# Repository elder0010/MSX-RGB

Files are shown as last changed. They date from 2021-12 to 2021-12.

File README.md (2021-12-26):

# TMS9929A / TMS9928A RGB
## A RGB demodulator for TMS9929A / TMS9928A chip, mostly used on MSX computers and Colecovision. 

This board outputs RGB+CSYNC from the original YPbPr chip channels of the TMS99 chip. 
Output from each color channel can be adjusted using a trimmer. 
Based on the [Universele interface RGB op MSX1 en SV.328](http://www.msxarchive.nl/pub/msx/mirrors/hanso/hwdoityourself/rgbmsx1.pdf). Mine fixes the emitter follower transistors of this version.
This repository contains the KiCad project and the Gerber files, the [PDF schematics](https://github.com/elder0010/msx_rgb/blob/main/TMS9929_RGB_Adapter.pdf) and the [BOM](https://github.com/elder0010/msx_rgb/blob/main/TMS9929_RGB_Adapter.csv) file.

## Features
- Each channel can be tuned
- Provides audio output pin
- Provides 5V output pin (if you want to use it with an RGB Scart cable for "modern" TVs)
- Fits into the MSX composite modulator slot
- Extremely cheap!

## Video
TMS99 RGB BOARD (https://www.youtube.com/watch?v=eCPy9jgGLzQ)

## Sample output (photo taken on BVM 20DU)
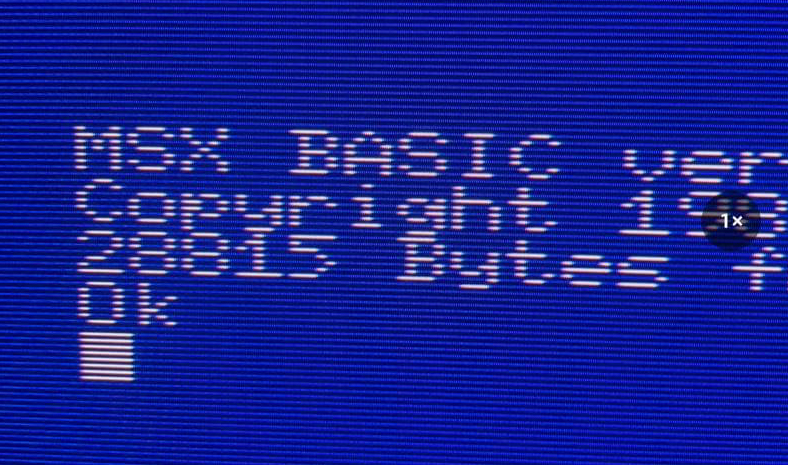
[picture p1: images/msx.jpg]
VIDEO OUT


## Assembled PCB
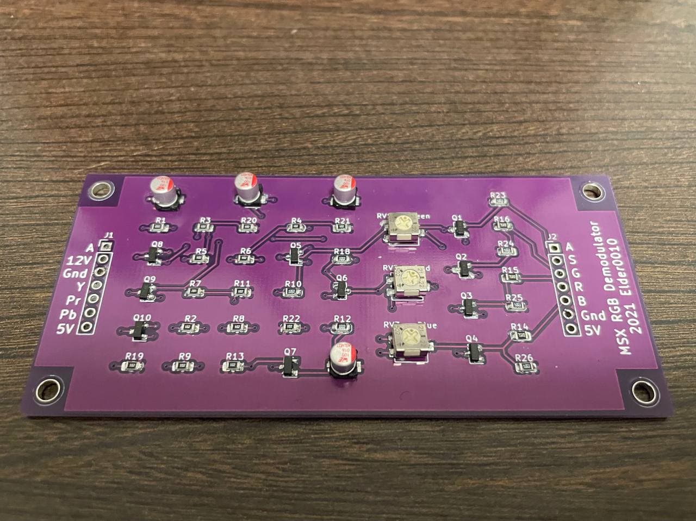
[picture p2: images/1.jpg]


## The PCB in a Phonola VG-8020
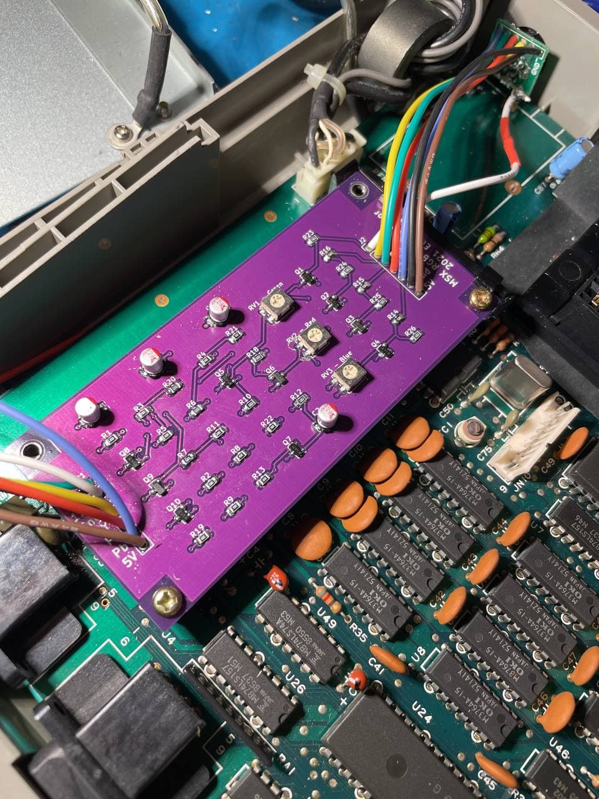
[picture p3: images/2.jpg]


## How to assemble
- Y, Pb, Pr signals must be taken directly from the TMS chip (pin 35,36,38 on TMS9928A or TMS9929A)
- Audio is from pin 4 of the AY38910
- 5V pin is optional: wire it only if you need to connect the computer to a scart TV.
- Removing the original composite modulator (on MSX) is not mandatory but encouraged: unfortunately it creates noises also on the RGB interface. Keep in mind that removing the modulator will disable the composite video and the RF video out of the machine.
- On the Phonola VG8020 I removed the RF modulator to make room for a 8 pin mini din connector. I used the [8pin Mini DIN to EuroSCART PACKAPUNCH cable for RGB modified consoles](https://www.retrogamingcables.co.uk/atari/8PIN-MINI-DIN-TO-RGB-EUROSCART-TIM-WORTHINGTON-NES-RGB-ATARI-2600-HAS-SUPERGUN-Sega-Game-Gear-Philips-CDi-Colecovision-Inte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). It's possible also to desolder the original composite out connector and use a 8 pin DIN connector to make it compatible with a Sega Genesis 1 SCART cable.

## External view of the mini din connector (RF modulator has been removed)
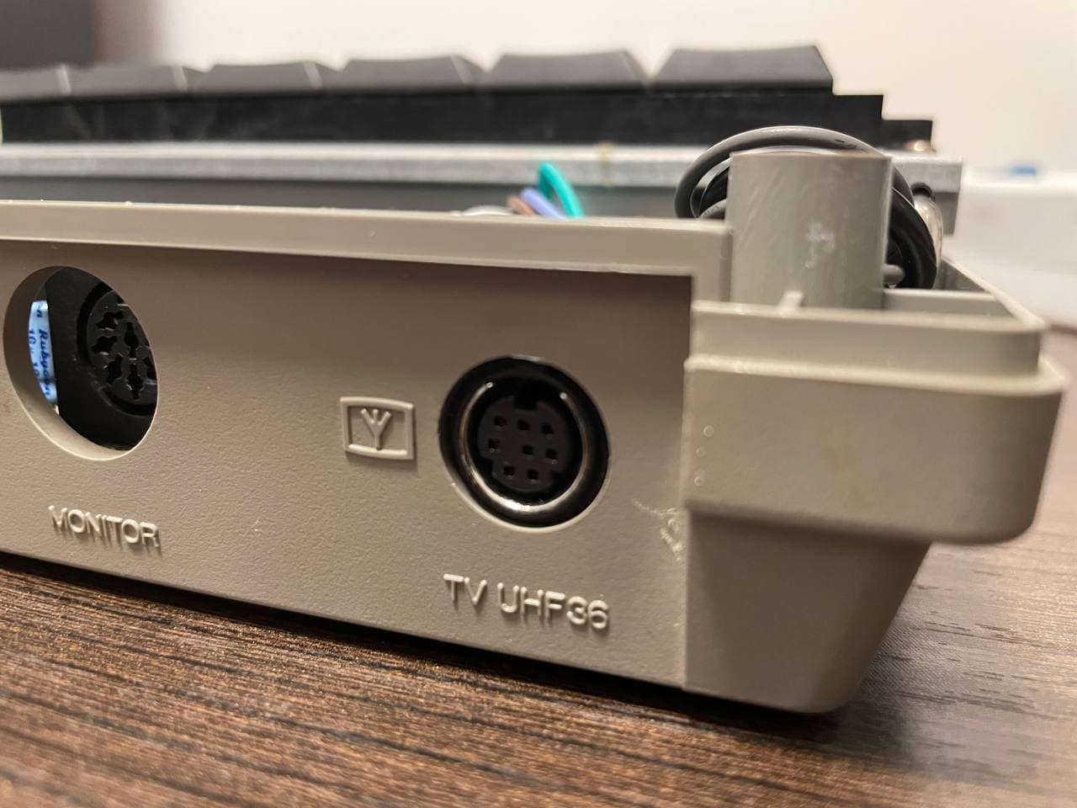
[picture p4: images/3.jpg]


## Perks
This board provides an RGB output for the TMS9929A / TMS9928A chip.
Although it's impossible to have 100% correct colours, it's possible to obtain a palette very close to the correct one in this way:
- Set each RGB trimmer to 0
- Turn up a little the RED and GREEN potentiometer until something visible appears on screen
- Turn up the BLUE potentiometer until the background becomes blueish - keep in mind that the blue channel is the most problematic one because of the TMS99x non-standard design
- Execute the command color 1,1 to set the screen and the text to black
- Notice how the black is blueish, and turn down the BLUE potentiometer until the background becomes less blueish ;)
- Execute the command color 15,4 to restore the screen to the default colours
- Repeat until you get a satisfactory result
- adjust the GREEN and the RED potentiometer accordingly 

In this way the palette should be close to the original.

## Compatibility
This board has been tested with TMS9929A (PAL) chip and TMS9928A (NTSC).

- PCB shape is the same of [TMS9929A RGB and Component adapter](https://hackaday.io/project/13056-tms9929a-rgb-and-component-adapter)
- Special thanks to [iz8dwf](https://www.youtube.com/iz8dwf)

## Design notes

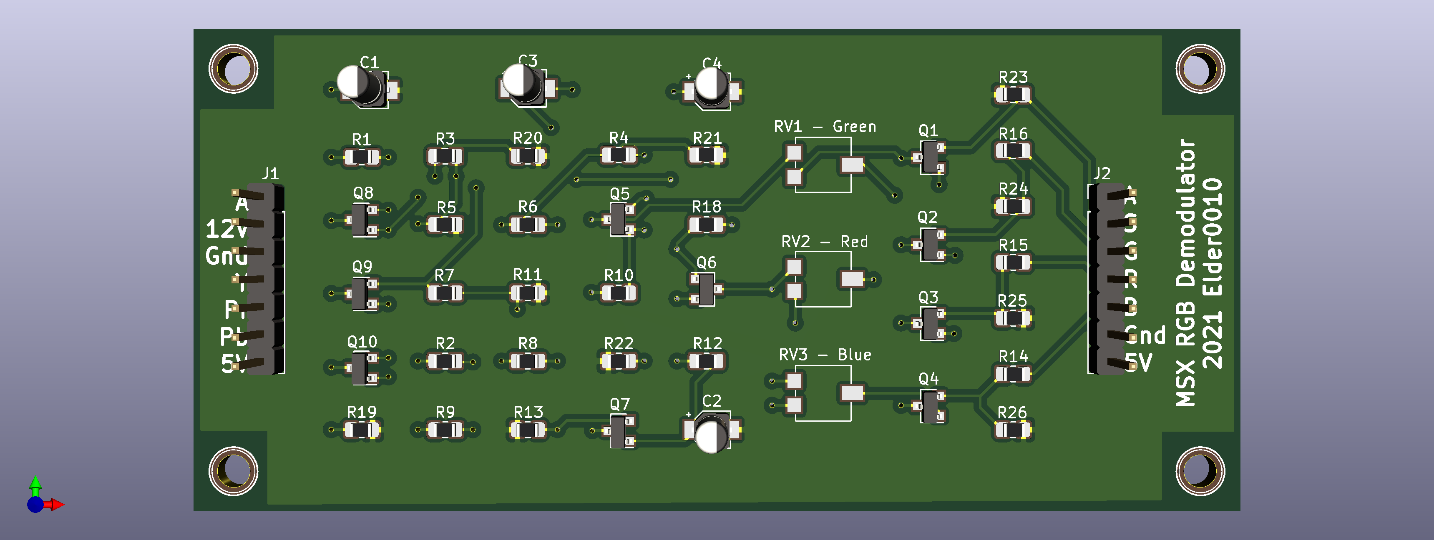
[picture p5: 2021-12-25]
TMS9929_RGB_Adapter.png

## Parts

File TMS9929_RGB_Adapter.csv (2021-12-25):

Id | Designator | Package | Quantity | Designation | Supplier and ref
1 | R5,R2,R6,R4,R20,R3,R7,R22,R13,R11,R8,R19,R9,R21 | R_0805_2012Metric_Pad1.20x1.40mm_HandSolder | 14 | 1K
2 | R26,R25,R24,R23 | R_0805_2012Metric_Pad1.20x1.40mm_HandSolder | 4 | 4K7 1/4W
3 | J2,J1 | PinHeader_1x07_P2.54mm_Vertical | 2 | Conn_01x07
4 | C4,C3,C2,C1 | CP_Elec_3x5.3 | 4 | 16V/10UF
5 | Q2,Q3,Q4,Q1,Q9,Q10,Q8,Q7,Q6,Q5 | SOT-23 | 10 | MMBT3904
6 | RV1 - Green,RV3 - Blue,RV2 - Red | Potentiometer_Vishay_TS53YL_Vertical | 3 | 5K
7 | R16,R14,R15 | R_0805_2012Metric_Pad1.20x1.40mm_HandSolder | 3 | 100R 1/4W
8 | R10,R18,R12 | R_0805_2012Metric_Pad1.20x1.40mm_HandSolder | 3 | 100K
9 | R1 | R_0805_2012Metric_Pad1.20x1.40mm_HandSolder | 1 | 2K2
10 | P6,P8,P9,P7 | 1pin | 4 | CONN_01X01

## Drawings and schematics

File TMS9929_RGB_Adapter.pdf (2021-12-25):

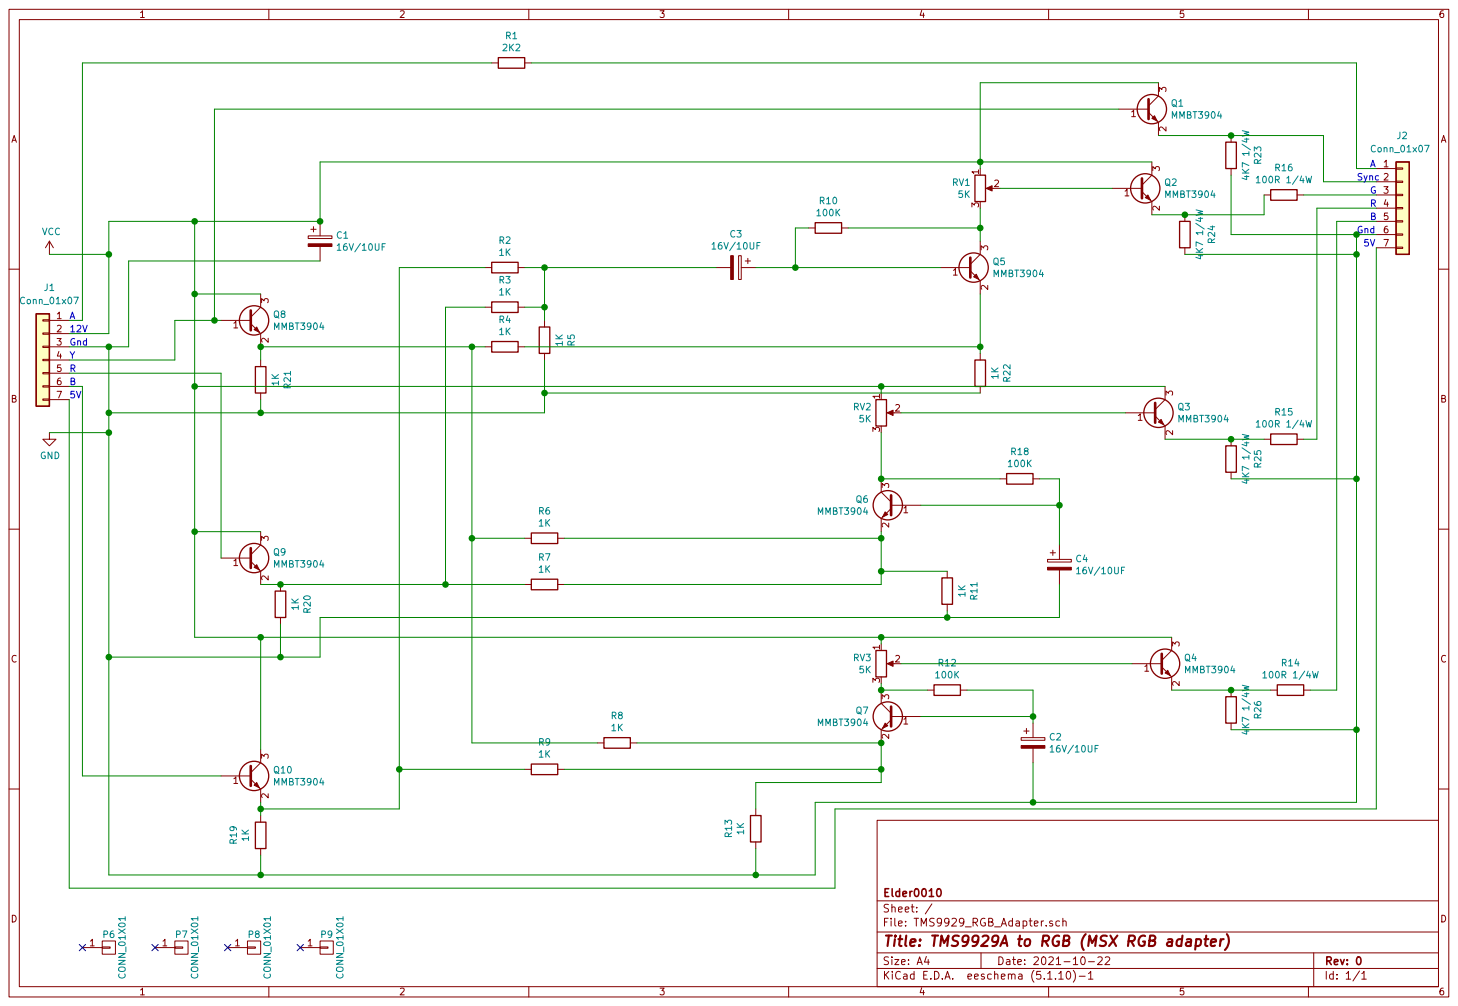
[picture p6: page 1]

Id: 1/1 Title: TMS9929A to RGB (MSX RGB adapter)

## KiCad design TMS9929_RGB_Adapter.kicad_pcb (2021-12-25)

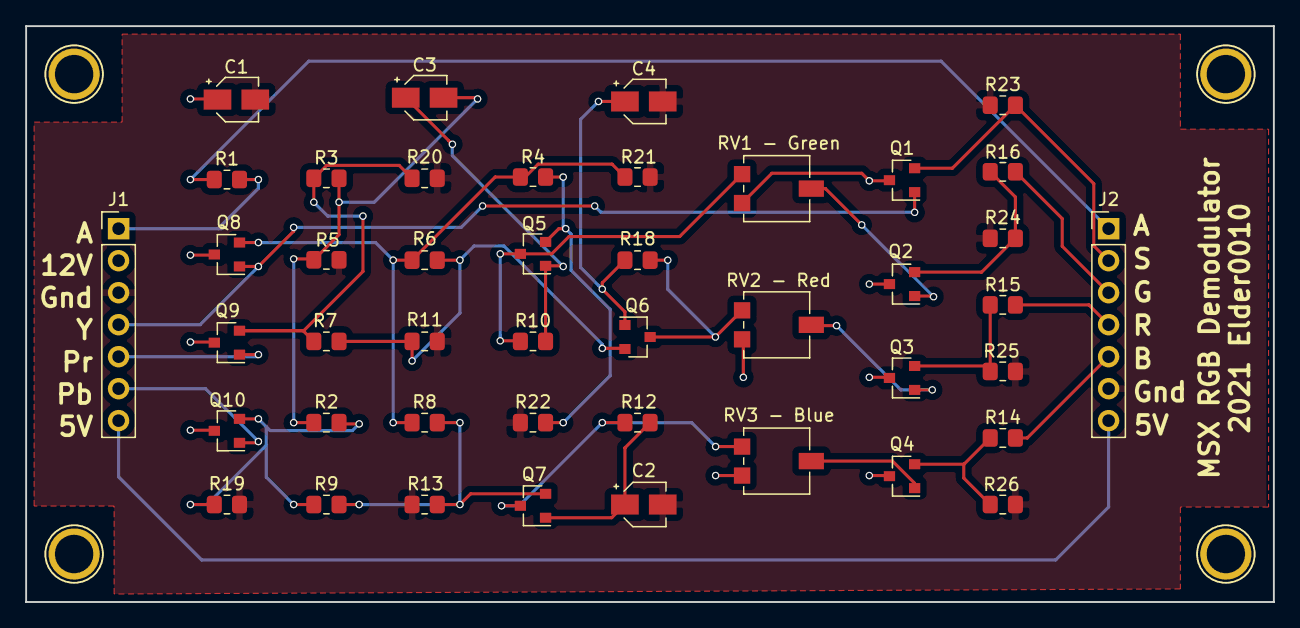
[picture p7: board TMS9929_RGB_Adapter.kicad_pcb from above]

Board: 2 copper layers, 99.1 x 45.7 mm, 48 parts (0 on the bottom side), 31 nets.

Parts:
C1, C2, C3, C4: 16V/10UF; CP_Elec_3x5.3
J1, J2: Conn_01x07; PinHeader_1x07_P2.54mm_Vertical
P6, P7, P8, P9: CONN_01X01; 1pin
Q1, Q2, Q3, Q4, Q5, Q6, Q7, Q8, Q9, Q10: MMBT3904; SOT-23
R1: 2K2; R_0805_2012Metric_Pad1.20x1.40mm_HandSolder
R2, R3, R4, R5, R6, R7, R8, R9, R11, R13, R19, R20, R21, R22: 1K; R_0805_2012Metric_Pad1.20x1.40mm_HandSolder
R10, R12, R18: 100K; R_0805_2012Metric_Pad1.20x1.40mm_HandSolder
R14, R15, R16: 100R 1/4W; R_0805_2012Metric_Pad1.20x1.40mm_HandSolder
R23, R24, R25, R26: 4K7 1/4W; R_0805_2012Metric_Pad1.20x1.40mm_HandSolder
RV1 - Green, RV2 - Red, RV3 - Blue: 5K; Potentiometer_Vishay_TS53YL_Vertical

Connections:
GND: C1.2, C2.2, C4.2, J1.3, J2.6, R5.1, R11.1, R13.2, R19.2, R20.1, R21.1, R22.1, R23.1, R24.1, R25.1, R26.1
unnamed: C2.1, Q7.1, R12.1
unnamed: C3.1, Q5.1, R10.2
unnamed: C3.2, R2.1, R3.1, R5.2
unnamed: C4.1, Q6.1, R18.1
unnamed: J1.1, R1.2
unnamed: J1.4, Q1.1, Q8.1
unnamed: J1.5, Q9.1
unnamed: J1.6, Q10.1
unnamed: J1.7, J2.7
unnamed: J2.1, R1.1
unnamed: J2.2, Q1.2, R23.2
unnamed: J2.3, R16.1
unnamed: J2.4, R15.1
unnamed: J2.5, R14.1
unnamed: Q2.1, RV1 - Green.2
unnamed: Q2.2, R16.2, R24.2
unnamed: Q3.1, RV2 - Red.2
unnamed: Q3.2, R15.2, R25.2
unnamed: Q4.1, RV3 - Blue.2
unnamed: Q4.2, R14.2, R26.2
unnamed: Q5.2, R4.1, R22.2
unnamed: Q5.3, R10.1, RV1 - Green.3
unnamed: Q6.2, R6.1, R7.1, R11.2
unnamed: Q6.3, R18.2, RV2 - Red.3
unnamed: Q7.2, R8.1, R9.1, R13.1
unnamed: Q7.3, R12.2, RV3 - Blue.3
unnamed: Q8.2, R4.2, R6.2, R8.2, R21.2
unnamed: Q9.2, R3.2, R7.2, R20.2
unnamed: Q10.2, R2.2, R9.2, R19.1
VCC: C1.1, J1.2, Q1.3, Q2.3, Q3.3, Q4.3, Q8.3, Q9.3, Q10.3, RV1 - Green.1, RV2 - Red.1, RV3 - Blue.1
